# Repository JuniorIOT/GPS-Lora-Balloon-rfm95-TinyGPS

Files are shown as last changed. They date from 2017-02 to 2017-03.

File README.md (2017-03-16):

# GPS-Lora-Balloon-rfm95-TinyGPS

## Libraries required
- TinyGPS       https://github.com/mikalhart/TinyGPS
- arduino-lmic  https://github.com/matthijskooijman/arduino-lmic

## Lora location transmittor with TinyGPS and rfm95 for Kaasfabriek project
```
  adjustment for fablab Kaasfabriek Junior IoT Baloon Challenge february 2017
             met leerling teams bij fablab de Kaasfabriek in Alkmaar
                     deze software op het internet is natuurlijk geheim...
                                  ...anders kunnen ze makkelijk afkijken!
```
See https://www.thethingsnetwork.org/labs/story/junior-iot-ballonnen-challenge

- Software plakker: Dennis --> dennis.ruigrok@gmail.com
- Educatie kletser: Marco --> marco@kaasfabriek.nl
- Regie en inspiratie: Kaasfabriek --> info at kaasfabriek punt nl

## Important
how to build your first node, practical soldering tips in nice pictures,
https://www.thethingsnetwork.org/labs/story/build-the-cheapest-possible-node-yourself
 --> you will need to use our pin mapping instead

## Pin mapping
```
    Suggested pin mapping:
    this new mapping puts the boards next to each other as shown in schema below,
          can be folded into compact stack or embedded in a business card size
    -----------------------------------------------------------------------------
                            ║                 ║ USB to serial programmer
                            ║3.3 TX RX GND 5V ║ while programming, power comes
                            ╚══╬══╬══╬══╬══╬══╝ from external supply to get
                               x  │  │  │  x    enough current for GPS
                               ┌──│──┘  │
                               │  │  x  │      ARDUINO pro mini
                          ╔═╬══╬══╬══╬══╬══╬═╗ 8Mhz 32kb                 ///////
      GPS unit            ║ G TX RX VCC GND B║ 3.3 volt                  helical
      NEO-6M              ║                  ║            gnd            868Mhz
      3.3 volt            ╬ TXD          RAW ╬x            │ 3v          antenna
     ╔═══════╗            ╬ RXD          GND ╬─black─60mm──┘ │           ///////
     ║       ║            ╬ RST          RST ╬x              │               │
     ║ (PPS) ╬x           ╬ GND          VCC ╬─red─48mm──────┘    3v   gnd   │
     ║   RXD ╬──pink─15mm─╬ 2 tx          A3 ╬───white─20mm───┐  red48  │    │
     ║   TXD ╬──brn─15mm──╬ 3 rx          A2 ╬──gray─16mm──┐  │  ┌─┘   blk60 │
     ║   GND ╬─blk30──┐   ╬ 4             A1 ╬─pur─14───┐  │  │  │      └─┐  │
    ┌╬   VCC ╬─red35┐ │   ╬ 5             A0 ╬──────┐ ╔═╬══╬══╬══╬══╬══╬══╬══╬═╗
    │║       ║      │ │   ╬ 6       (led) 13*╬─────┐│ ║D2 D1 D0 3V D4 D3 GND ANT
    │╚═══════╝     3v │   ╬ 7        MISO 12*╬────┐│└──pink─18mm────┐          ║
    │                gnd  ╬ 8        MOSI 11*╬───┐│└──ora─20mm───┐  │ RFM95    ║
    │                     ╬ 9             10 ╬─┐ └│──yel─23mm─┐  │  │ 3.3 volt ║
    │ ┌─────────────┐     ║                  ║ │  └─grn─27─┐  │  │  │ (10 euro)║
    └─┤ gps antenna │     ╚═══╬══╬══╬══╬══╬══╝ └──blue─22──│──│──│──│──┐       ║
      └─────────────┘                                 ║    │  │  │  │  │       ║
                                                      ╚═╬══╬══╬══╬══╬══╬══╬══╬═╝
                                                      GND MI MO SCK NS RE D5 GND
    GPS arduino RFM95       LIPO Protect
    | |   | |    | |         ╔═══════╗        switch               ╔═════════╗
    └─|───┴─|────┴─|─3x─red──╬3v   B+╬─┬─red17─╣/╠──red─lipo─30mm──╬+  1 CELL║
      └─────┴──────┴3x─black─╬gnd  B-╬─│─┬─────────black─lipo─??mm─╬-  LIPO  ║
                             ╚═══════╝ │ │                         ╚═════════╝
                                      JST female connector
                                      to LiPo charger with protect
```

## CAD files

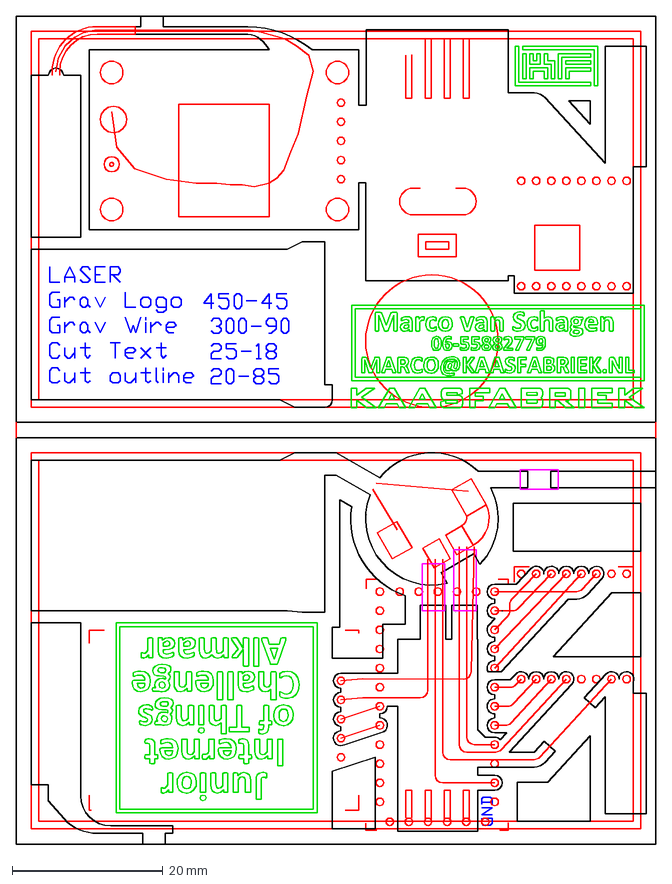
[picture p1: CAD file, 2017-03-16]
visitekaartje_GPS_290170316.dxf
85.0 x 110.0 mm

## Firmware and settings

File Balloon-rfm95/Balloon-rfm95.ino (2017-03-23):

/*******************************************************************************
 * Copyright (c) 2015 Thomas Telkamp and Matthijs Kooijman
 *
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
 * Do not forget to define the radio type correctly in config.h. in lmic library
 *
 * Modified By DenniZr & Marco van Schagen
 *******************************************************************************/ 
 // TODO: We will create a new TTN account 'Kaasfabriek' at some later day where our teams wil be building their stuff.
 
//#define DEBUG     // if DEBUG is defined, some code is added to display some basic debug info

//#include "LowPower.h"   // help to do power save on the arduino  https://github.com/rocketscream/Low-Power
//#include <JeeLib.h>  // Include library containing low power functions
//ISR(WDT_vect) { Sleepy::watchdogEvent(); } // Setup for low power waiting

//////////////////////////////////////////////
// GPS libraries, mappings and things
//////////////////////////////////////////////
#include <SoftwareSerial.h> 
#include <TinyGPS.h>

SoftwareSerial ss(3, 2);  // ss RX, TX --> gps TXD, RXD
TinyGPS gps;
long gps_fix_count = 0;
long gps_nofix_count = 0;

//////////////////////////////////////////////
// LMIC and RFM95 mapping and things
//////////////////////////////////////////////
#include <lmic.h>
#include <hal/hal.h>
const unsigned  TX_INTERVAL = 120;  // previously tested with 300=5 minutes; 15 hours battery time but many gps losses // transmit interval, 5 minutes is healthy according to TTN rules; however 60 sec is still very well possible (risk is getting the device blacklisted rest of day)
const dr_t LMIC_DR_sequence[] = {DR_SF10, DR_SF7, DR_SF7, DR_SF7, DR_SF7, DR_SF7, DR_SF9, DR_SF7, DR_SF7, DR_SF7, DR_SF7, DR_SF7 };      //void LMIC_setDrTxpow (dr_t dr, s1_t txpow)
const int  LMIC_DR_sequence_count = 12;
int  LMIC_DR_sequence_index = 0;
const  lmic_pinmap lmic_pins = { .nss = 14,    .rxtx = LMIC_UNUSED_PIN,    .rst = 10,    .dio = {17, 16, 15}, };

const unsigned message_size = 12;  // including byte[0]
uint8_t  mydata[message_size];  // including byte[0]
// byte 0, 1, 2      Latitude       3 bytes: -90 to +90 degrees rescaled to 0 - 16777215
// byte 3, 4, 5      Longitude      3 bytes: -180 to + 180 degrees rescaled to 0 - 16777215
// byte 6, 7         Altitude       2 bytes: in meters. 0 - 65025 meter
// byte 8            GPS DoP        1 byte: in 0.1 values.  0 - 25.5 DoP
// byte 9            Arduino VCC    1 byte in 50ths Volt. 0 - 5.10 volt
// byte 10           cpu temp       1 byte  value -100. -100 - 155 deg C
// byte 11           time to fix    1 byte: special finction, 10% accuracy 1 sec - 7 hours
      // 0..60 sec  at 1 sec interval <==> values 0 .. 60 
      // 1..10 min at 5 sec interval  <==> values 60 ..  168
      // 10..60 min at 1 min interval <==> values 168 .. 218
      // 1..7 hour at 10 min interval <==> values 218 ..254; 255 is "more than 7 hours"

// THIS BYTE STRING NEEDS A DECODER FUNCTION IN TTN:
/* * function Decoder (bytes) {
  var _lat = ((bytes[0] << 16) + (bytes[1] << 8) + bytes[2]) / 16777215.0 * 180.0 - 90;
  var _lng = ((bytes[3] << 16) + (bytes[4] << 8) + bytes[5]) / 16777215.0 * 360.0 - 180;
  var _alt = (bytes[6] << 8) + bytes[7];
  var _acc = bytes[8] / 10.0;
  var _VCC = bytes[9] / 50;
  var _tempCPU = bytes[10] -100;
  var _time_to_fix_bin = bytes[11];
  var _time_to_fix;
  if (_time_to_fix_bin>=218) { _time_to_fix = 60*60+(_time_to_fix_bin-218)*600 }
  else if (_time_to_fix_bin>=168) { _time_to_fix = 10*60+(_time_to_fix_bin-168)*60 }
  else if (_time_to_fix_bin>=60) {  _time_to_fix = 60+(_time_to_fix_bin-60)*5 }
  else  {_time_to_fix = _time_to_fix_bin }
  
      // 0..60 sec  at 1 sec interval <==> values 0 .. 60 
      // 1..10 min at 5 sec interval  <==> values 60 ..  168
      // 10..60 min at 1 min interval <==> values 168 .. 218
      // 1..7 hour at 10 min interval <==> values 218 ..254; 255 means "more than 7 hours"
      
  var _inputHEX = bytes[0].toString(16)+' '+bytes[1].toString(16)+' '+bytes[2].toString(16)
                  +' '+bytes[3].toString(16)+' '+bytes[4].toString(16)+' '+bytes[5].toString(16)
                  +' '+bytes[6].toString(16)+' '+bytes[7].toString(16)+' '+bytes[8].toString(16)
                  +' / '+bytes[9].toString(16)+' '+bytes[10].toString(16)+' '+bytes[11].toString(16);
  return {
    gps_lat: _lat,
    gps_lng: _lng,
    gps_alt: _alt,
    gps_prec: _acc,
    arduino_VCC: _VCC,
    arduino_temp: _tempCPU,
    time_to_fix: _time_to_fix,
    payload: _inputHEX
  };
}
*/

// // do not keep radio active to listen to return message in RX2. see https://github.com/matthijskooijman/arduino-lmic/blob/master/src/lmic/config.h
// #define DISABLE_JOIN     // Uncomment this to disable all code related to joining
#define DISABLE_PING     // Uncomment this to disable all code related to ping
#define DISABLE_BEACONS  // Uncomment this to disable all code related to beacon tracking.// Requires ping to be disabled too 

#include <SPI.h>  //MISO MOSI SCK stuff
#include "keys.h"  // the personal keys to identify our own nodes

static  osjob_t sendjob;

// os_ interfaces for callbacks only used in over-the-air activation, so functions can be left empty here
void  os_getArtEui (u1_t* buf) { }
void  os_getDevEui (u1_t* buf) { }
void  os_getDevKey (u1_t* buf) { } 

int TX_COMPLETE_was_triggered = 0;  // 20170220 added to allow full controll in main Loop

//////////////////////////////////////////////////////////
//// Kaasfabriek routines for gps
////////////////////////////////////////////

void put_gpsvalues_into_sendbuffer(long l_lat, long l_lon, long l_alt, int hdopNumber) {    

  const double shift_lat =    90 * 1000000;        // range shift from -90M..90M into 0..180M
  const double max_old_lat = 180 * 1000000;        // max value for lat is now 180M
  const double max_3byte =        16777215;        // max value that fits in 3 bytes
  double lat_float = l_lat;                        // put the 4byte LONG into a more precise floating point to prevent round-off effect in calculation
  lat_float = (lat_float + shift_lat) * max_3byte / max_old_lat; // rescale into 3 byte integer range
  uint32_t LatitudeBinary = lat_float;             // clips off anything after the decimal point
  
  Serial.println(F("\n\nInto send buffer "));
  
  #ifdef DEBUG
  Serial.print(F(" LAT=")); Serial.print( l_lat); 
  Serial.print(F(" => ( ")); Serial.print( lat_float);    
  Serial.print(F(" + ")); Serial.print( shift_lat);    
  Serial.print(F(" ) * ")); Serial.print( max_3byte);    
  Serial.print(F(" / ")); Serial.print( max_old_lat);   
  Serial.print(F(" = ")); Serial.print( LatitudeBinary);  
  Serial.print(F(" = HEX ")); Serial.println( LatitudeBinary, HEX); 
  #endif 
  
  const double shift_lon =   180 * 1000000;        // range shift from -180M..180M into 0..360M
  const double max_old_lon = 360 * 1000000;        // max value longitude is now 360M
  double lon_float = l_lon;                        // put the 4byte LONG into a precise floating point memory space
  lon_float = (lon_float + shift_lon) * max_3byte / max_old_lon; // rescale into 3 byte integer range
  uint32_t LongitudeBinary = lon_float;             // clips off anything after the decimal point
  
  #ifdef DEBUG
  Serial.print(F(" LON =")); Serial.print( l_lon); 
  Serial.print(F(" => ( ")); Serial.print( lon_float);    
  Serial.print(F(" + ")); Serial.print( shift_lon);    
  Serial.print(F(" ) * ")); Serial.print( max_3byte);    
  Serial.print(F(" / ")); Serial.print( max_old_lon);   
  Serial.print(F(" = ")); Serial.print( LongitudeBinary);  
  Serial.print(F(" = HEX ")); Serial.println( LongitudeBinary, HEX);  
  #endif
  
  uint16_t altitudeGps = l_alt/100;         // altitudeGps in meters, l_alt from tinyGPS is integer in centimeters
  if (l_alt<0) altitudeGps=0;               // unsigned int wil not allow negative values and warps them to huge number, needs to be zero'ed
  
  #ifdef DEBUG    
  Serial.print(F(" alt=")); Serial.print( l_alt );
  Serial.print(F(" => ")); Serial.print( altitudeGps);
  Serial.print(F(" = HEX ")); Serial.println( altitudeGps, HEX);  
  #endif
  
  uint8_t accuracy = hdopNumber/10;   // from TinyGPS horizontal dilution of precision in 100ths, TinyGPSplus seems the same in 100ths as per MNEMA string
  
  #ifdef DEBUG
  Serial.print(F(" hdop=")); Serial.print( hdopNumber);
  Serial.print(F(" => ")); Serial.print( accuracy);
  Serial.print(F(" = HEX ")); Serial.println( accuracy, HEX);  
  #endif
  
  mydata[0] = ( LatitudeBinary >> 16 ) & 0xFF;
  mydata[1] = ( LatitudeBinary >> 8 ) & 0xFF;
  mydata[2] = LatitudeBinary & 0xFF;

  mydata[3] = ( LongitudeBinary >> 16 ) & 0xFF;
  mydata[4] = ( LongitudeBinary >> 8 ) & 0xFF;
  mydata[5] = LongitudeBinary & 0xFF;

  // altitudeGps in meters into unsigned int
  mydata[6] = ( altitudeGps >> 8 ) & 0xFF;
  mydata[7] = altitudeGps & 0xFF;

  // hdop in tenths of meter
  mydata[8] = accuracy & 0xFF;
  
  #ifdef DEBUG
  Serial.println(F("  Alkmaar = CA DA F. 83 5E 9. 0 .. .. " ));     
  Serial.println(F("  Zero    = 7F FF FF 7F FF FF 0 0 0 " ));
  #endif
  Serial.print(F(" Mydata[]=[ "));
  for(int i=0; i<message_size; i++) {
    Serial.print(mydata[i], HEX); Serial.print(F(" "));
  }
  Serial.println(F("]"));
}

void process_gps_values() { 
  // retrieve values from GPS library, and if valid put them into send buffer
  // NOT USE the float numbers from library to keep memory as low as possible
  long l_lat, l_lon, l_alt;
  unsigned long age; 
  int hdopNumber;  
  bool GPS_values_are_valid = true;
  
  gps.get_position(&l_lat, &l_lon, &age);  // lat -90.0 .. 90.0 as a 4 byte float, lon -180 .. 180 as a 4 byte float, age in 1/1000 seconds as a 4 byte unsigned long
  l_alt = gps.altitude();    // signed float altitude in meters
  hdopNumber = gps.hdop();   // int 100ths of a meter

  // check if possibly invalid
  if (l_lat == TinyGPS::GPS_INVALID_ANGLE)    GPS_values_are_valid = false;
  if (l_lon == TinyGPS::GPS_INVALID_ANGLE)    GPS_values_are_valid = false;
  if (hdopNumber == TinyGPS::GPS_INVALID_HDOP) GPS_values_are_valid = false;
  if (age == TinyGPS::GPS_INVALID_AGE)         GPS_values_are_valid = false;
  
  if (l_alt == TinyGPS::GPS_INVALID_ALTITUDE)  GPS_values_are_valid = false;   // if alt, hdop remain giving errors, possibly the GPS character read misses every start few characters of every feed. Solution: make the code lighter so it returns quicker to character read. Or process a bit of buffer while doing other actions, see TinyGPS example.

  // if valid, put into buffer
  if (GPS_values_are_valid) put_gpsvalues_into_sendbuffer( l_lat, l_lon, l_alt, hdopNumber);
   
  #ifdef DEBUG
  Serial.println();
  Serial.print(F("Data: "));
  if (GPS_values_are_valid) Serial.print(F("(valid) "));
  if (!GPS_values_are_valid) Serial.print(F("(** INVALID"));
  if (l_lat == TinyGPS::GPS_INVALID_ANGLE)    {Serial.print(F(" lat=")); Serial.print(l_lat);}
  if (l_lon == TinyGPS::GPS_INVALID_ANGLE)    {Serial.print(F(" lon=")); Serial.print(l_lon);}
  if (hdopNumber == TinyGPS::GPS_INVALID_HDOP) {Serial.print(F(" hdop=")); Serial.print(hdopNumber);}
  if (age == TinyGPS::GPS_INVALID_AGE)         {Serial.print(F(" age=")); Serial.print(age);}
  if (l_alt == TinyGPS::GPS_INVALID_ALTITUDE)  {Serial.print(F(" alt=")); Serial.print(l_alt);}
  if (!GPS_values_are_valid) Serial.print(F(" **) "));
  Serial.print(F(" LAT, LON="));
  Serial.print( l_lat);   
  Serial.print(F(", "));
  Serial.print( l_lon); 
  Serial.print(F(" hdop="));
  Serial.print( hdopNumber);
  Serial.print(F(" alt="));
  Serial.print( l_alt );
  Serial.print(F(" AGE="));
  Serial.print(age);
  Serial.println();
  #endif  // debug
  
}

void gps_calcChecksum(byte *checksumPayload, byte payloadSize) {
  byte CK_A = 0, CK_B = 0;
  for (int i = 0; i < payloadSize ;i++) {
    CK_A = CK_A + *checksumPayload;
    CK_B = CK_B + CK_A;
    checksumPayload++;
  }
  *checksumPayload = CK_A;
  checksumPayload++;
  *checksumPayload = CK_B;
}

// Send a byte array of UBX protocol to the GPS  https://ukhas.org.uk/guides:ublox6
void sendUBX(uint8_t *MSG, uint8_t len) {
  for(int i=0; i<len; i++) {
    ss.write(MSG[i]);
    Serial.print(MSG[i], HEX);
  }
  ss.println();
}

// Calculate expected UBX ACK packet and parse UBX response from GPS  https://ukhas.org.uk/guides:ublox6
boolean getUBX_ACK(uint8_t *MSG) {
  uint8_t b;
  uint8_t ackByteID = 0;
  uint8_t ackPacket[10];
  unsigned long startTime = millis();
  Serial.print(F(" Reading ACK "));
 
  // Construct the expected ACK packet    
  ackPacket[0] = 0xB5;  // header
  ackPacket[1] = 0x62;  // header
  ackPacket[2] = 0x05;  // class
  ackPacket[3] = 0x01;  // id
  ackPacket[4] = 0x02;  // length
  ackPacket[5] = 0x00;
  ackPacket[6] = MSG[2];  // ACK class
  ackPacket[7] = MSG[3];  // ACK id
  ackPacket[8] = 0;   // CK_A
  ackPacket[9] = 0;   // CK_B
 
  // Calculate the checksums
  for (uint8_t i=2; i<8; i++) {
    ackPacket[8] = ackPacket[8] + ackPacket[i];
    ackPacket[9] = ackPacket[9] + ackPacket[8];
  } 
  while (1) { 
    // Test for success
    if (ackByteID > 9) {
      // All packets in order!
      Serial.println(F("\n(GPS cmd okay)"));
      return true;
    }
 
    // Timeout if no valid response in 3 seconds
    if (millis() - startTime > 3000) { 
      Serial.println(F("\n(GPS cmd timeout)"));
      //ss.flush();  // try to fix
      return false;
    }
 
    // Make sure data is available to read
    if (ss.available()) {
      b = ss.read();
 
      // Check that bytes arrive in sequence as per expected ACK packet
      if (b == ackPacket[ackByteID]) { 
        ackByteID++;
        Serial.print(b, HEX);
      } 
      else {
        ackByteID = 0;  // Reset and look again, invalid order
      }
 
    }
  }
}

void gps_init() {
  // load the send buffer with dummy location 0,0. This location 0,0 is recognized as dummy by TTN Mapper and will be ignored
  put_gpsvalues_into_sendbuffer( 0, 0, 0, 0);
  
  // GPS serial starting
  ss.begin(9600);         // software serial with GPS module. Reviews tell us software serial is not best choice; 
                          // https://www.pjrc.com/teensy/td_libs_TinyGPS.html explains to use UART Serial or NewSoftSerial 

  //   https://ukhas.org.uk/guides:ublox6
  // THE FOLLOWING COMMAND SWITCHES MODULE TO 4800 BAUD
  //ss.print(F("$PUBX,41,1,0007,0003,4800,0*13\r\n")); 
  //ss.begin(4800);
  //ss.flush();

  //gps_requestColdStart();  // DO NOT USE: it seems this does a FACTORY RESET and delays getting a solid fix
  gps_SetMode_gpsRfOn();
  gps_setStrings();
  gps_setNavMode(4); // 2=stationary, 3=pedestrian, 4=auto, 5=Sea, 6=airborne 1g, 7=air 2g, 8=air 4g
  
  gps_setPowerMode(1);  // 1=max power, 2=eco, 3=cyclic power save
  gps_read_until_fix_or_timeout(60 * 60);  // after factory reset, time to first fix can be 15 minutes (or multiple).  gps needs to acquire full data which is sent out once every 15 minutes; sat data sent out once every 5 minutes

  //assume fix was found, go to airborne
  // Lessons learned,
  //       my gps does not find fix while on the ground in mode 6
  //       does find fix in mode 7, but no re-fix after RF-off and RF-on
  //       so for now we keep in mode 4 OR experiment with powermodes instead of RF_off
  // gps_setNavMode(7); // 2=stationary, 3=pedestrian, 4=auto, 5=Sea, 6=airborne 1g, 7=air 2g, 8=air 4g -- with 6 no 2d fix supported
  // gps_read_until_fix_or_timeout(30 * 60);  // after factory reset, time to first fix can be 15 minutes (or multiple).  gps needs to acquire full data which is sent out once every 15 minutes; sat data sent out once every 5 minutes
  //gps_setPowerMode(2);
}

void gps_read_until_fix_or_timeout(unsigned long timeOut) {
  Serial.print(F("\nRead GPS until fix is found or time-out at "));
  Serial.print(timeOut);
  Serial.println(F(" sec"));
  
  unsigned long timeoutTime = millis() + timeOut * 1000;
  long gps_fix_count_old = gps_fix_count;
  
  while(gps_fix_count==gps_fix_count_old && millis() < timeoutTime) {
    gps_read_5sec();
  }
  
  if (gps_fix_count == gps_fix_count_old) {
    Serial.println(F("\nNO FIX FOUND"));
    gps_nofix_count++; // we want to know how many times no fix was found
  } else {
    Serial.println(F("\nFix was found"));
  }
}
    
void gps_read_chars(int countdown) {
  while (countdown > 0) {
    if(ss.available()) {       
      countdown--;
      char c = ss.read();
      Serial.write(c); 
      if (gps.encode(c)) {   // Did a new valid sentence come in?
        gps_fix_count++;
        process_gps_values();
        Serial.print(F(" [fix] ")); 
      }
    }
  }
}

void gps_read_5sec() {
  Serial.print(F("\nGPS fixes: "));
  Serial.print(gps_fix_count);
  Serial.print(F(" non-fixes: "));
  Serial.print(gps_nofix_count);
  Serial.println(F(". Reading GPS. "));

  char c;
  long gps_fix_count_old = gps_fix_count;
  unsigned long startTime = millis();
  do {   
    while (ss.available()) {
      char c = ss.read();
      //#ifdef DEBUG
      Serial.write(c); 
      //#endif
      
      if (gps.encode(c)) { // Did a new valid sentence come in?
          gps_fix_count++;
          process_gps_values();
          Serial.print(F(" [fix] "));            
       }          
    }
  } while (millis() - startTime < 5000); // reading for 5 seconds

  if (gps_fix_count == gps_fix_count_old) gps_nofix_count++; // we want to know how many times no fix was found
}
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
void loop() {
  unsigned long startTime = millis();
  
  Serial.println(F("\n\nRead GPS"));

  gps_read_until_fix_or_timeout(2*60); // try up to 5 minutes to get a fix
  gps_read_5sec();  // 5 sec extra to get stronger fix

  Serial.println(F("\nRead values"));
  put_VCC_and_Temp_into_sendbuffer();
  
  int Time_till_now = (millis() - startTime) / 1000 ; 
  if (!has_sent_allready) {
    has_sent_allready = true;
    Time_till_now = (millis() - device_startTime) / 1000 ; // only the first message tells the world the device boot time till first fix/send
  }
  put_TimeToFix_into_sendbuffer( Time_till_now );
  
  Serial.println(F("\nSending"));
  do_send();
  Serial.println(F("Waiting.."));  
  while (TX_COMPLETE_was_triggered == 0) {
    os_runloop_once();     // system picks up just the first job from all scheduled jobs, needed for the scheduled and interrupt tasks
  }
  TX_COMPLETE_was_triggered = 0;
  Serial.println(F("TX_COMPL"));
  
  
  gps_SetMode_gpsRfOff();

  Serial.print(F("\nSleep GPS "));
  //=--=-=---=--=-=--=-=--=  START SLEEP HERE -=-=--=-=-=-=-==-=-=-

  unsigned long processedTime = millis() - startTime;
  long sleeptime = TX_INTERVAL  - (processedTime / 1000);
  if ( sleeptime < 0 ) sleeptime = 0;
//  Serial.print(" TX_INTERVAL=" );
//  Serial.print(TX_INTERVAL);
//  Serial.print(" processedTime=" );
//  Serial.print(processedTime);
//  Serial.print(" sleeptime=" );
  Serial.print(sleeptime );
  Serial.println(F(" sec"));
  
  //LowPower.powerDown(SLEEP_4S, ADC_OFF, BOD_OFF);    // this kind of sleep does not work
  //Serial.println(F("sleep2 "));
  //Sleepy::loseSomeTime(8000);  // max 60.000 (60 sec)  // this kind of sleep does not work
  //Serial.println(F("delay "));
  
  delay(sleeptime * 1000);
  
  //=--=-=---=--=-=--=-=--=  SLEEP IS COMPLETED HERE -=-=--=-=-=-=-==-=-=-
  
//    gps_SetMode_gpsOn();
  gps_SetMode_gpsRfOn();
  Serial.println(F("Sleep done"));
}

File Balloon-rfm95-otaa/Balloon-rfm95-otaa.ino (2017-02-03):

/*******************************************************************************
 * Copyright (c) 2015 Thomas Telkamp and Matthijs Kooijman
 *
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
 * This example sends a valid LoRaWAN packet with payload "Hello,
 * world!", using frequency and encryption settings matching those of
 * the The Things Network.
 *
 * This uses OTAA (Over-the-air activation), where where a DevEUI and
 * application key is configured, which are used in an over-the-air
 * activation procedure where a DevAddr and session keys are
 * assigned/generated for use with all further communication.
 *
 * Note: LoRaWAN per sub-band duty-cycle limitation is enforced (1% in
 * g1, 0.1% in g2), but not the TTN fair usage policy (which is probably
 * violated by this sketch when left running for longer)!

 * To use this sketch, first register your application and device with
 * the things network, to set or generate an AppEUI, DevEUI and AppKey.
 * Multiple devices can use the same AppEUI, but each device has its own
 * DevEUI and AppKey.
 *
 * Do not forget to define the radio type correctly in config.h.
 *
 *******************************************************************************/
 // TODO: add GPS flightmode. Good test script seems available here:  https://ukhas.org.uk/guides:ublox6
 // TODO: GPS powersafe. https://ukhas.org.uk/guides:ublox_psm
// todo: if no good read from GPS in last 2 minutes, then reset arduino as a manual reset fixes the problem?? Or auto-reset every 120 minutes. investigate
// TODO: We will also create a new account 'Kaasfabriek' at some later day where our teams wil be building their stuff.
// TODO: each few messages, send one at high power


#define DEBU //G     // if DEBUG is defined, some code is added to display some basic debug info
#define DE //BUG_XL  // if DEBUG_XL is defined, some code is added to display more detailed debug info

#include <lmic.h>
#include <hal/hal.h>
#include <SPI.h>
#include <SoftwareSerial.h>  
  //https://www.pjrc.com/teensy/td_libs_TinyGPS.html explains to use NewSoftSerial however https://www.arduino.cc/en/Reference/softwareSerial explains that newsoftserial is part of SoftwareSerial in arduino version 1.0 and up
#include <TinyGPS.h>
#include "keys.h"

//uint8_t mydata[9];   // mydata[9] allows you to read and write to mydata[0] .. mydata[8]. Higher numbers work but are invalid.
uint8_t mydata[14];  // a few bytes added to the memory buffer to play with
//const unsigned message_size = 9;  // 9 bytes are needed into the ttn tracker service
const unsigned message_size =11; //sending too large message makes the ttntracker ignore it, allowing us to see payload at ttnonsole
void os_getArtEui (u1_t* buf) { memcpy_P(buf, APPEUI, 8);}
void os_getDevEui (u1_t* buf) { memcpy_P(buf, DEVEUI, 8);}
void os_getDevKey (u1_t* buf) {  memcpy_P(buf, APPKEY, 16);}

static osjob_t sendjob;
// Schedule TX event every this many seconds (might become longer due to duty cycle limitations).
// https://www.thethingsnetwork.org/forum/t/limitations-data-rate-packet-size-30-seconds-uplink-and-10-messages-downlink-per-day-fair-access-policy/1300
//   Golden rule: 30 seconds air-time per device per day
//    For 10 bytes of payload (plus 13 bytes overhead), this is whispered to imply:
//    approx 20 messages per day at SF12  --> approx one per hour 
//    500 messages per day at SF7  --> 500 / 24 = 20 per hour, or 3 minutes in-between sends (average)
//  for 9 bytes message, the 500 count is upped to 523 or 22 messages per hour, or 2:45 minute average between sends
//
//  For each step-up in SF Spreading factor the air-time doubles, so the allowed number of messages gets divided in half
//    meaning for example you can send one SF8 for the same cost as two SF7 messages
//  Simply one setting and one interval would be easiest.
//
//      spreading | avg time between | nbr of messages
//      factor    | 9 byte sends     | per hour or per day
//     -----------|------------------|-----------------
//      DR_SF7    |  2:45 minutes    |  22 per hour, 528 per day
//      DR_SF8    |  5:30 minutes    |  11 per hour, 264 per day
//      DR_SF9    |  11 minutes      |  5.5 per hour, 132 per day
//      DR_SF10   |  22 minutes      |  2.75 per hour, 66 per day
//      DR_SF11   |  44 minutes      |  1.3 per hour, 33 per day
//      DR_SF12   |  1:28 hours      |              16.5 per day
// Sending pattern would be:
//     a. All messages are SF7, interval 2:45 minutes = 165 seconds (setting is at 105); in tests a setting of 130 results in 180 sec intervals so the library adds 50 sec.
//
//  However in tests we found that coverage in the Netherlands still varies, so we vant a few loud sends per hour.
//  Let's make a mix. You can do what you prefer... I'd prefer to see where my balloon is once every 5 or 6 minutes, and one loud send every half hour.
//     b. Loudest. One SF12 message - will fill up the hour and will not allow more messages. Not desirable.
//     c. Less loud. One SF11 uses 44 minutes, leaves budget for 6 messages as SF7. Total of 7 messages per hour, not frequent enough.
//     d. Even less loud. One DR_SF10 is 22 minutes of budget, one SF9 adds 11 minutes; leaves budget to send another 10 messages as SF7 to add another 27.5 min. 
//        Total 12 messages in one hour. 
//        interval 5 minutes, message stream: DR_SF7, DR_SF7, DR_SF7, DR_SF7, DR_SF7, DR_SF10, DR_SF7, DR_SF7, DR_SF7, DR_SF7, DR_SF7, DR_SF9 
//  let's build and test scenario (d)  with interval at 5 min = 300 sec (setting at 250)
 
//const unsigned TX_INTERVAL = 20; 
const unsigned TX_INTERVAL = 250;  // transmit interval, in tests it seems the library adds some 30-50 seconts to this value 
dr_t LMIC_DR_sequence[] = {DR_SF7, DR_SF10, DR_SF7, DR_SF7, DR_SF7, DR_SF7, DR_SF7, DR_SF9, DR_SF7, DR_SF7, DR_SF7, DR_SF7 };      //void LMIC_setDrTxpow (dr_t dr, s1_t txpow)
int LMIC_DR_sequence_count = 12;
int LMIC_DR_sequence_index = 0;

// Pin mapping, adjusted to get wires to same side as NISO & NOSI
const lmic_pinmap lmic_pins = {
    .nss = 14,                 // mapping for NSS, was: 10, new: 14=A0 (is digital 14)
    .rxtx = LMIC_UNUSED_PIN,
    .rst = 10,                  // mapping for reset. was: 5, new: 10
    .dio = {15, 16, 17},          // mapping for DIO0, DIO1, DIO2  was: 2, 3, 4  new: A1=15, A2=16, A3=17
};
TinyGPS gps;
SoftwareSerial ss(3, 2);  // RX, TX    to connect arduino RX, TX --> GPS TXD, RXD    was 8, 9; new: 3, 2
//SoftwareSerial ss(9, 8);    // or try if wires have been reversed, can be tested by reviewing output in serial/debug window
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

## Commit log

2017-01-14 GPS power on pin 7
2017-01-15 toch niet gps power op pin 7
2017-01-15 marco lot of debug
    The payload would result in geo markers all over the place. Added so
    many debugging to confirm the calculations were up to par with example
    JP. Tthe correct data is available when the call reaches into do_send.
    Somewhere between the library and ttn console it does get garbled.
    [Balloon-rfm95.ino]
2017-01-17 overhaul. Read newest correct gps only.
    Read and review each burst of gps data.
    Store to send buffer newest correct gps only.
    Debugging tweaks.
    [Balloon-rfm95.ino]
2017-01-17 change negative altitude to zero
    unsigned int wil not allow negative values and warps them to huge
    number, needs to be zero'ed
    [Balloon-rfm95.ino]
2017-01-22 added wiring diagram, adjusted pin mapping
    changing to wiring due to frying out the whole hardware, taking the
    opportunity to try easier wiring
2017-01-22 updated
    working version
    adjusted debugging code
    switched female/male JST connector to fix error
    [Balloon-rfm95.ino]
2017-02-03 Test for otaa - dont forget reversed keys for EUI's
    [Balloon-rfm95-otaa.ino]
2017-02-10 GPS powersave succesfully tested
2017-02-20 intermediate save
    reformattting code to get rid of scheduled tasks/interrupt chain style
    LMIC controll. Adding send routine in main loop, to allow better power
    save options.
2017-02-20 gps setting samples added
2017-02-25 gps routine, send ttn, memory optimize
    print(F("")) helps to reduce dynamic memory by keeping those strings in
    program memory only
2017-02-25 gps first fix to one hour
    gps not able to get a fix
    [Balloon-rfm95.ino]
2017-02-28 battery time 6h to 10h
2017-03-01 gps init, nav mode 4 -> 7
    nav mode 4 -> 6 does not re-fix in first 5 minutes !!! after sleep
    [Balloon-rfm95.ino]
2017-03-01 fix err in sleeptime
    [Balloon-rfm95.ino]
2017-03-02 Added "time to fix", TTN decoding function
    Time to fix is time from "device on" or "device wake-up" till gps fix
    was obtained, in seconds. Sent in a single byte value (0 to 255) to send
    a value ranging from 1 seconds to 7 hours.
    [Balloon-rfm95.ino]
2017-03-16 add dxf
    [visitekaartje_GPS_290170316.dxf]
